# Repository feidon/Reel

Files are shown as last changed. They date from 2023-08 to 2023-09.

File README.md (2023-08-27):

# ErgoSNM Keyboard



*ErgoSNM* \- a split ergonomic keyboard that aims to make people leave their mouse behind.

Features introduction, build guides and more information can be found in the [Docs:book:](https://siderakb.github.io/docs/ergosnm/)

## Footprint

If `key-switches.pretty` folder is empty, execute `git submodule update --init` to clone submodule.

## Firmware

- Vial QMK: [siderakb/vial-qmk](https://github.com/siderakb/vial-qmk/tree/siderakb/main/keyboards/siderakb/ergosnm) (*siderakb/main* branch)

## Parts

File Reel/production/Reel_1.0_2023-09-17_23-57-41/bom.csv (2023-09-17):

Designator | Footprint | Quantity | Value | LCSC Part #
C1, C2, C6, C7 | 0402 | 4 | 1uF | C52923
C10, C11, C12, C13, C14, C15, C16, C3, C8, C9 | 0402 | 10 | 100nF | C307331
C4, C5 | 0402 | 2 | 20pF | C1554
D1, D10, D11, D12, D13, D14, D15, D16, D17, D18, D19, D2, D20, D21, D22, D23, D24, D25, D26, D27, D28, D29, D3, D30, D31, D32, D33, D34, D35, D36, D37, D38, D39, D4, D40, D41, D42, D43, D44, D45, D46, D47, D5, D6, D7, D8, D9 | D_SOD-123 | 47 | 1N4148 | C81598
F1 | 0805 | 1 | 500mA, 6V | C269104
J1 | USB_C_Receptacle_HRO_TYPE-C-31-M-12 | 1 | USB_C_Receptacle_USB2.0 | C165948
J2 | PinHeader_1x04_P2.54mm_Vertical_debug | 1 | NA_Conn_01x04_Female
KEY1, KEY10, KEY11, KEY12, KEY13, KEY15, KEY16, KEY17, KEY18, KEY19, KEY2, KEY20, KEY21, KEY22, KEY23, KEY24, KEY27, KEY28, KEY29, KEY3, KEY30, KEY31, KEY32, KEY33, KEY34, KEY35, KEY36, KEY37, KEY4, KEY45, KEY46, KEY47, KEY5, KEY6, KEY7, KEY8, KEY9 | MX-Solderable-1U | 37 | SW_Push_45deg
KEY14, KEY38, KEY39, KEY40, KEY41, KEY44, KEY48 | MX-Solderable-1.25U | 7 | SW_Push_45deg
KEY25, KEY26 | MX-Solderable-1.75U | 2 | SW_Push_45deg
KEY42 | MX-Solderable-2U-ReversedStabilizers | 1 | SW_Push_45deg
KEY43 | MX-Solderable-2.25U-ReversedStabilizers | 1 | SW_Push_45deg
R1, R2 | 0402 | 2 | 5.1k | C25905
R3, R4 | 0603 | 2 | 27 | C25190
R5, R7 | 0402 | 2 | 1k | C11702
R6, R8 | 0402 | 2 | 10k | C25744
SW1 | SW_SPST_TL3342 | 1 | BOOT
SW2 | SW_SPST_TL3342 | 1 | RESET
U1 | SOT-23-5 | 1 | RT9013-33GB | C47773
U2 | SOT-23-6 | 1 | SRV05-4 | C85364
U3 | SOIC-8_5.23x5.23mm_P1.27mm | 1 | W25Q128JVS | C97521
U4 | QFN-56-1EP_7x7mm_P0.4mm_EP3.2x3.2mm | 1 | RP2040 | C2040
Y1 | Crystal_SMD_2520-4Pin_2.5x2.0mm | 1 | 12MHz | C2149204

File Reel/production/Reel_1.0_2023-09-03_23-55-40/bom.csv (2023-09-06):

Designator | Footprint | Quantity | Value | LCSC Part #
C1, C2 | 0603 | 2 | 1µ | C19666
C10, C11, C12, C13, C14, C15, C16, C19, C7, C8 | 0402 | 10 | 100nF | C1525
C17, C5, C6 | 0402 | 3 | 1uF | C52923
C3, C4 | 0402 | 2 | 15pF | C1548
D1, D10, D11, D12, D13, D14, D15, D16, D17, D18, D19, D2, D20, D21, D22, D23, D24, D25, D26, D27, D28, D29, D3, D30, D31, D32, D33, D34, D35, D36, D37, D38, D39, D4, D40, D41, D42, D43, D44, D45, D46, D5, D6, D7, D8, D9 | D_SOD-123 | 46 | 1N4148 | C81598
D1001 | D_SOD-323 | 1 | B5817 | C123899
F1 | 0603 | 1 | Polyfuse | C69679
FB1 | 0603 | 1 | FerriteBead_Small | C98288
J1 | USB_C_Receptacle_HRO_TYPE-C-31-M-12 | 1 | USB_C_Receptacle_USB2.0 | C165948
J2 | PinHeader_1x04_P2.54mm_Vertical_debug | 1 | NA_Conn_01x04_Female
KEY1, KEY10, KEY11, KEY12, KEY13, KEY15, KEY16, KEY17, KEY18, KEY19, KEY2, KEY20, KEY21, KEY22, KEY23, KEY24, KEY27, KEY28, KEY29, KEY3, KEY30, KEY31, KEY32, KEY33, KEY34, KEY35, KEY36, KEY37, KEY4, KEY5, KEY6, KEY7, KEY8, KEY9 | MX-Solderable-1U | 34 | SW_Push_45deg
KEY14, KEY38, KEY39, KEY40, KEY41, KEY44, KEY45, KEY46 | MX-Solderable-1.25U | 8 | SW_Push_45deg
KEY25, KEY26 | MX-Solderable-1.75U | 2 | SW_Push_45deg
KEY42 | MX-Solderable-2U-ReversedStabilizers | 1 | SW_Push_45deg
KEY43 | MX-Solderable-2.25U-ReversedStabilizers | 1 | SW_Push_45deg
LED1, LED2 | SK6812-MINI-E | 2 | SK6812
R1, R2, R7 | 0402 | 3 | 5.1k | C25905
R10, R5, R8 | 0402 | 3 | 10k | C25744
R11 | 0402 | 1 | 330 | C105875
R3, R6 | 0402 | 2 | 27 | C25100
R4, R9 | 0402 | 2 | 1k | C11702
SW1 | SW_SPST_TL3342 | 1 | BOOT
SW2 | SW_SPST_TL3342 | 1 | RESET
U1 | SOT-23-5 | 1 | XC6210B332MR-G | C82942
U2 | SOT-666 | 1 | USBLC6-2P6 | C2827693
U3 | SOIC-8_5.23x5.23mm_P1.27mm | 1 | W25Q128JVS | C190862
U4 | QFN-56-1EP_7x7mm_P0.4mm_EP3.2x3.2mm | 1 | RP2040 | C2040
Y1 | Crystal_SMD_2520-4Pin_2.5x2.0mm | 1 | 12MHz | C2149204

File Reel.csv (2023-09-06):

ID | 指示符 | 封裝 | 數量 | 名稱 | 供應商和參考
1 | LED1,LED2,LED3 | LED_SK6805-EC15_1.5x1.5mm_P0.6mm_handsolder(1) | 3 | SK6805-EC15
2 | KEY9,KEY17,KEY16,KEY15,KEY12,KEY11,KEY33,KEY32,KEY7,KEY29,KEY1,KEY35,KEY19,KEY13,KEY8,KEY6,KEY36,KEY28,KEY21,KEY31,KEY18,KEY22,KEY10,KEY20,KEY5,KEY23,KEY3,KEY2,KEY4,KEY37,KEY30,KEY24,KEY27,KEY34 | MX-Solderable-1U | 34 | SW_Push_45deg
3 | KEY38,KEY44,KEY46,KEY41,KEY39,KEY45,KEY14,KEY40 | MX-Solderable-1.25U | 8 | SW_Push_45deg
4 | J2 | PinHeader_1x04_P2.54mm_Vertical_debug | 1 | NA_Conn_01x04_Female
5 | KEY25,KEY26 | MX-Solderable-1.75U | 2 | SW_Push_45deg
6 | KEY42 | MX-Solderable-2U-ReversedStabilizers | 1 | SW_Push_45deg
7 | KEY43 | MX-Solderable-2.25U-ReversedStabilizers | 1 | SW_Push_45deg
8 | D33,D14,D28,D16,D18,D3,D46,D11,D24,D20,D41,D40,D31,D42,D39,D32,D25,D7,D23,D37,D1,D19,D27,D26,D13,D44,D45,D15,D8,D34,D17,D30,D29,D43,D10,D4,D2,D9,D38,D12,D35,D36,D6,D22,D21,D5 | D_SOD-123 | 46 | 1N4148
9 | R7,R1,R2 | R_0402_1005Metric | 3 | 5.1k
10 | U4 | QFN-56-1EP_7x7mm_P0.4mm_EP3.2x3.2mm | 1 | RP2040
11 | R6,R3 | R_0402_1005Metric | 2 | 27
12 | C4,C3 | C_0402_1005Metric | 2 | 15pF
13 | C17 | C_0402_1005Metric | 1 | 1µ
14 | C13,C8,C19,C10,C11,C7,C16,C14,C15,C12 | C_0402_1005Metric | 10 | 100nF
15 | SW2 | SW_SPST_TL3342 | 1 | RESET
16 | R4,R9 | R_0402_1005Metric | 2 | 1k
17 | C2,C1 | C_0603_1608Metric | 2 | 1µ
18 | R11 | R_0402_1005Metric | 1 | 330
19 | Y1 | Crystal_SMD_2520-4Pin_2.5x2.0mm | 1 | 12MHz
20 | J1 | USB_C_Receptacle_HRO_TYPE-C-31-M-12 | 1 | USB_C_Receptacle_USB2.0
21 | F1 | Fuse_0603_1608Metric | 1 | Polyfuse
22 | U2 | SOT-666 | 1 | USBLC6-2P6
23 | U3 | SOIC-8_5.23x5.23mm_P1.27mm | 1 | W25Q128JVS
24 | FB1 | L_0603_1608Metric | 1 | FerriteBead_Small
25 | R10,R5,R8 | R_0402_1005Metric | 3 | 10k
26 | C6,C5 | C_0402_1005Metric | 2 | 1uF
27 | SW1 | SW_SPST_TL3342 | 1 | BOOT
28 | D1001 | D_SOD-323 | 1 | B5817
29 | U1 | SOT-23-5 | 1 | XC6210B332MR-G

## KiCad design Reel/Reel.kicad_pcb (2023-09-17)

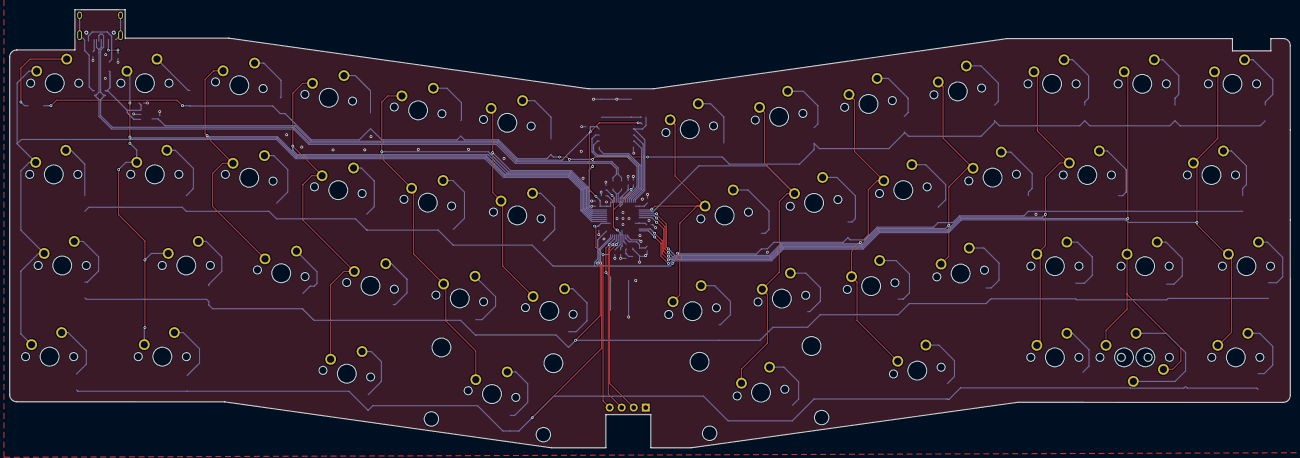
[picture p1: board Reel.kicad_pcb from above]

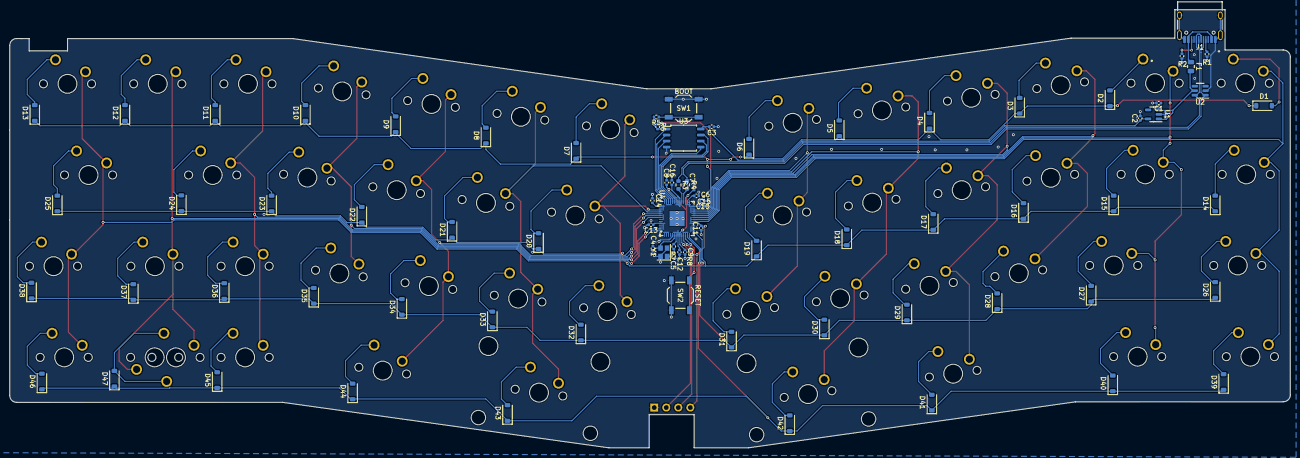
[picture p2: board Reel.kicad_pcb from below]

Board: 2 copper layers, 270.4 x 92.5 mm, 129 parts (80 on the bottom side), 88 nets.

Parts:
C1, C2, C6, C7: 1uF; C_0402_1005Metric
C3, C8, C9, C10, C11, C12, C13, C14, C15, C16: 100nF; C_0402_1005Metric
C4, C5: 20pF; C_0402_1005Metric
D1, D2, D3, D4, D5, D6, D7, D8, D9, D10, D11, D12, D13, D14, D15, D16, D17, D18, D19, D20, D21, D22, D23, D24, D25, D26, D27, D28, D29, D30, D31, D32, D33, D34, D35, D36, D37, D38, D39, D40, D41, D42, D43, D44, D45, D46, D47: 1N4148; D_SOD-123
F1: 500mA, 6V; Fuse_0805_2012Metric
J1: USB_C_Receptacle_USB2.0; USB_C_Receptacle_HRO_TYPE-C-31-M-12
J2: NA_Conn_01x04_Female; PinHeader_1x04_P2.54mm_Vertical_debug
KEY1, KEY2, KEY4, KEY5, KEY6, KEY7, KEY8, KEY9, KEY10, KEY11, KEY12, KEY13, KEY15, KEY16, KEY17, KEY18, KEY19, KEY20, KEY21, KEY22, KEY23, KEY24, KEY27, KEY28, KEY29, KEY47: SW_Push_45deg; MX-Solderable-1U
KEY14, KEY48: SW_Push_45deg; MX-Solderable-1.25U
KEY25, KEY26: SW_Push_45deg; MX-Solderable-1.75U
R1, R2: 5.1k; R_0402_1005Metric
R3, R4: 27; R_0603_1608Metric
R5, R7: 1k; R_0402_1005Metric
R6, R8: 10k; R_0402_1005Metric
SW1: BOOT; SW_SPST_TL3342
SW2: RESET; SW_SPST_TL3342
U1: RT9013-33GB; SOT-23-5
U2: SRV05-4; SOT-23-6
U3: W25Q128JVS; SOIC-8_5.23x5.23mm_P1.27mm
U4: RP2040; QFN-56-1EP_7x7mm_P0.4mm_EP3.2x3.2mm
Y1: 12MHz; Crystal_SMD_2520-4Pin_2.5x2.0mm
locked: locked; MX-Solderable-1.25U
locked#2, locked#7, locked#10, locked#16: locked; MX-Solderable-1.25U
locked#3, locked#4, locked#5, locked#6, locked#8, locked#11, locked#13, locked#14, locked#15, locked#17, locked#18: locked; MX-Solderable-1U
locked#9: locked; MX-Solderable-2U-ReversedStabilizers
locked#12: locked; MX-Solderable-2.25U-ReversedStabilizers

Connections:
+1V1: C7.1, C8.1, C9.1, U4.23 (DVDD), U4.45 (VREG_VOUT), U4.50 (DVDD)
+3V3: C2.1, C3.1, C6.1, C10.1, C11.1, C12.1, C13.1, C14.1, C15.1, C16.1, J2.1, R6.1, R8.1, U1.5 (VOUT), U3.8 (VCC), U4.1 (IOVDD), U4.10 (IOVDD), U4.22 (IOVDD), U4.33 (IOVDD), U4.42 (IOVDD), U4.43 (ADC_AVDD), U4.44 (VREG_IN), U4.48 (USB_VDD), U4.49 (IOVDD)
+5V: C1.1, F1.2, U1.1 (VIN), U1.3 (EN), U2.5 (VP)
/RP2040/BOOT: R5.1, SW1.2
/RP2040/QSPI_D0: U3.5 (DI(IO0)), U4.53 (QSPI_SD0)
/RP2040/QSPI_D1: U3.2 (DO(IO1)), U4.55 (QSPI_SD1)
/RP2040/QSPI_D2: U3.3 (IO2), U4.54 (QSPI_SD2)
/RP2040/QSPI_D3: U3.7 (IO3), U4.51 (QSPI_SD3)
/RP2040/QSPI_SCLK: U3.6 (CLK), U4.52 (QSPI_SCLK)
/RP2040/QSPI_SS: R5.2, R6.2, U3.1 (~CS), U4.56 (QSPI_SS)
/RP2040/SWCLK: J2.3, U4.24 (SWCLK)
/RP2040/SWDIO: J2.2, U4.25 (SWD)
/RP2040/~RESET: R8.2, SW2.2, U4.26 (RUN)
/USB_D+: J1.A6 (D+), J1.B6 (D+), R3.1, U2.6 (IO4)
/USB_D-: J1.A7 (D-), J1.B7 (D-), R4.1, U2.1 (IO1)
COL_0: KEY1.1, KEY14.1, KEY26.1, U4.34 (GPIO22), locked#10.1
COL_1: KEY2.1, KEY15.1, KEY27.1, U4.35 (GPIO23), locked#16.1
COL_2: KEY16.1, KEY28.1, U4.36 (GPIO24), locked#13.1
COL_3: KEY4.1, KEY17.1, KEY29.1, U4.37 (GPIO25), locked#7.1
COL_4: KEY5.1, KEY18.1, U4.38 (GPIO26_ADC0), locked#9.1, locked#17.1
COL_5: KEY6.1, KEY19.1, U4.39 (GPIO27_ADC1), locked#11.1
COL_6: KEY7.1, KEY20.1, U4.3 (GPIO1), locked#4.1
COL_7: KEY8.1, KEY21.1, U4.4 (GPIO2), locked#3.1, locked#12.1
COL_8: KEY9.1, KEY22.1, U4.5 (GPIO3), locked#2.1, locked#18.1
COL_9: KEY10.1, KEY23.1, U4.6 (GPIO4), locked#6.1
COL_10: KEY11.1, KEY24.1, U4.7 (GPIO5), locked#8.1, locked#14.1
COL_11: KEY12.1, KEY47.1, KEY48.1, U4.13 (GPIO10), locked#15.1
COL_12: KEY13.1, KEY25.1, U4.14 (GPIO11), locked.1, locked#5.1
GND: C1.2, C2.2, C3.2, C4.1, C5.1, C6.2, C7.2, C8.2, C9.2, C10.2, C11.2, C12.2, C13.2, C14.2, C15.2, C16.2, J1.A1 (GND), J1.A12 (GND), J1.B1 (GND), J1.B12 (GND), J1.S1 (SHIELD), J2.4, R1.2, R2.2, SW1.1, SW2.1, U1.2 (GND), U2.2 (VN), U3.4 (GND), U4.19 (TESTEN), U4.57 (GND), Y1.2, Y1.4
unnamed: C5.2, R7.1, Y1.1
unnamed: D1.2 (A), KEY1.2
unnamed: D2.2 (A), KEY2.2
unnamed: D3.2 (A), locked#13.2
unnamed: D4.2 (A), KEY4.2
unnamed: D5.2 (A), KEY5.2
unnamed: D6.2 (A), KEY6.2
unnamed: D7.2 (A), KEY7.2
unnamed: D8.2 (A), KEY8.2
unnamed: D9.2 (A), KEY9.2
unnamed: D10.2 (A), KEY10.2
unnamed: D11.2 (A), KEY11.2
unnamed: D12.2 (A), KEY12.2
unnamed: D13.2 (A), KEY13.2
unnamed: D14.2 (A), KEY14.2
unnamed: D15.2 (A), KEY15.2
unnamed: D16.2 (A), KEY16.2
unnamed: D17.2 (A), KEY17.2
unnamed: D18.2 (A), KEY18.2
unnamed: D19.2 (A), KEY19.2
unnamed: D20.2 (A), KEY20.2
unnamed: D21.2 (A), KEY21.2
unnamed: D22.2 (A), KEY22.2
unnamed: D23.2 (A), KEY23.2
unnamed: D24.2 (A), KEY24.2
unnamed: D25.2 (A), KEY25.2
unnamed: D26.2 (A), KEY26.2
unnamed: D27.2 (A), KEY27.2
unnamed: D28.2 (A), KEY28.2
unnamed: D29.2 (A), KEY29.2
unnamed: D30.2 (A), locked#17.2
unnamed: D31.2 (A), locked#11.2
unnamed: D32.2 (A), locked#4.2
unnamed: D33.2 (A), locked#3.2
unnamed: D34.2 (A), locked#18.2
unnamed: D35.2 (A), locked#6.2
unnamed: D36.2 (A), locked#8.2
unnamed: D37.2 (A), locked#15.2
unnamed: D38.2 (A), locked.2
unnamed: D39.2 (A), locked#10.2
unnamed: D40.2 (A), locked#16.2
unnamed: D41.2 (A), locked#7.2
unnamed: D42.2 (A), locked#9.2
unnamed: D43.2 (A), locked#12.2
unnamed: D44.2 (A), locked#2.2
unnamed: D45.2 (A), locked#14.2
unnamed: D46.2 (A), locked#5.2
unnamed: D47.2 (A), KEY47.2, KEY48.2
unnamed: J1.A5 (CC1), R1.1
unnamed: J1.B5 (CC2), R2.1
unnamed: R4.2, U4.46 (USB_DM)
unnamed: R3.2, U4.47 (USB_DP)
unnamed: C4.2, U4.20 (XIN), Y1.3
unnamed: R7.2, U4.21 (XOUT)
ROW_0: D1.1 (K), D2.1 (K), D3.1 (K), D4.1 (K), D5.1 (K), D6.1 (K), D7.1 (K), D8.1 (K), D9.1 (K), D10.1 (K), D11.1 (K), D12.1 (K), D13.1 (K), U4.40 (GPIO28_ADC2)
ROW_1: D14.1 (K), D15.1 (K), D16.1 (K), D17.1 (K), D18.1 (K), D19.1 (K), D20.1 (K), D21.1 (K), D22.1 (K), D23.1 (K), D24.1 (K), D25.1 (K), U4.29 (GPIO18)
ROW_2: D26.1 (K), D27.1 (K), D28.1 (K), D29.1 (K), D30.1 (K), D31.1 (K), D32.1 (K), D33.1 (K), D34.1 (K), D35.1 (K), D36.1 (K), D37.1 (K), D38.1 (K), U4.28 (GPIO17)
ROW_3: D39.1 (K), D40.1 (K), D41.1 (K), D42.1 (K), D43.1 (K), D44.1 (K), D45.1 (K), D46.1 (K), D47.1 (K), U4.27 (GPIO16)
VBUS: F1.1, J1.A4 (VBUS), J1.A9 (VBUS), J1.B4 (VBUS), J1.B9 (VBUS)

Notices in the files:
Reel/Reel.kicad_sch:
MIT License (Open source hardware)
